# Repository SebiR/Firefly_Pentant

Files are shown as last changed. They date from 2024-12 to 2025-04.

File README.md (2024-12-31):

# Firefly pendant
A green LED inside a small glass bottle looks like a caught firefly.
It is battery powered and can be used as decoration or jewelry.

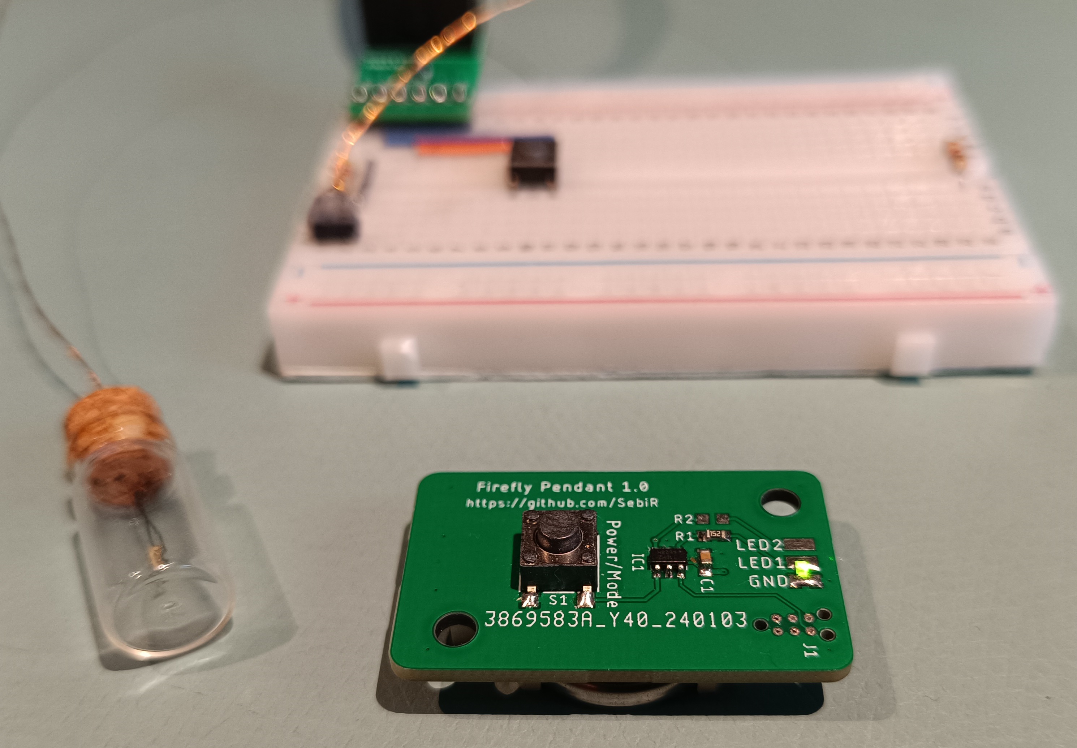
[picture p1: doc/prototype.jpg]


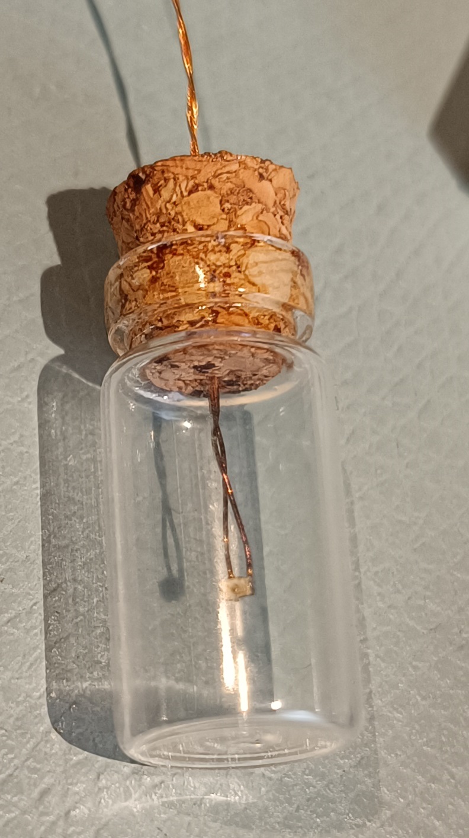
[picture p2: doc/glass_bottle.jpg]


## Features
* powered by a single CR2032
* Can drive two LEDs 
* Can be switched on and off with a button
* Uses deep sleep for long battery life

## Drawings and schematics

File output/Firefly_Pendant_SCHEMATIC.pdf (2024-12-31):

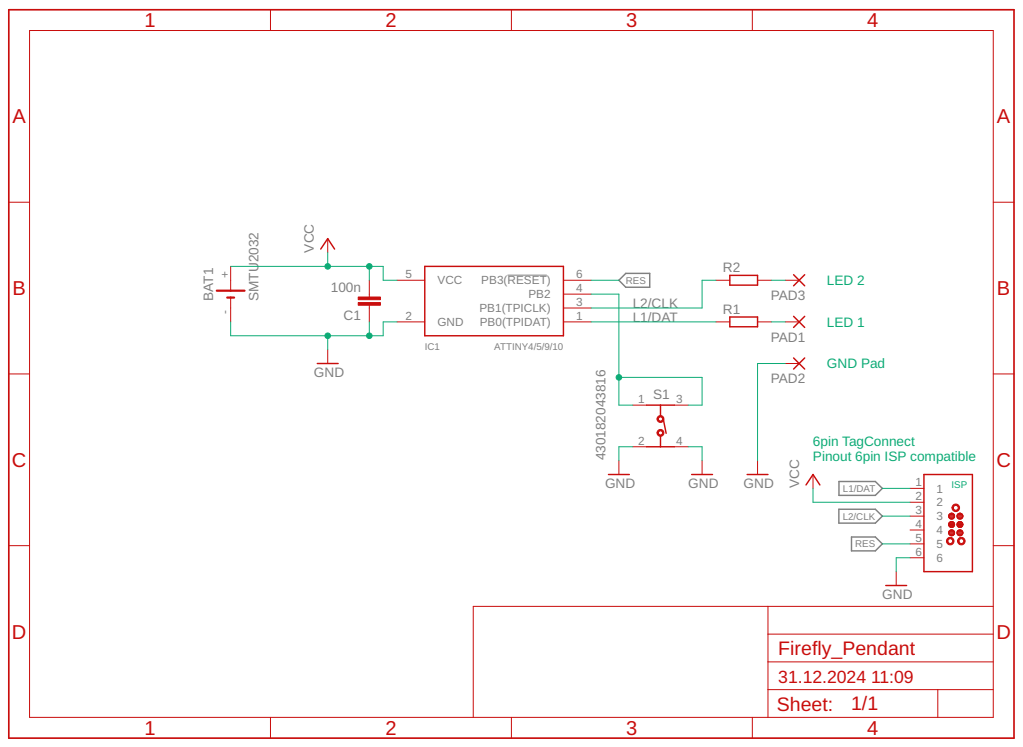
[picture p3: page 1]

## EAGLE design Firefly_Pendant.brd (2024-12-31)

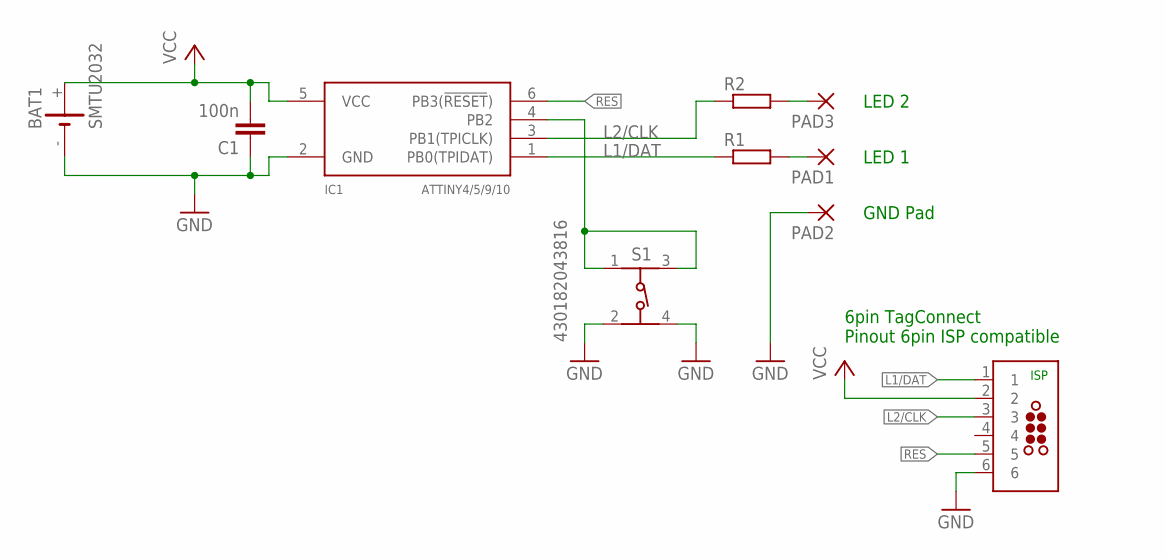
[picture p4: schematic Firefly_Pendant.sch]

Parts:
BAT1: SMTU2032
C1: 100n; C0603
IC1: ATTINY4/5/9/10; SOT23-6
J1: TAG-CONNECT_TC2030-MCP-NL
PAD1, PAD2, PAD3: WIREPADSMD1,27-254; SMD1,27-2,54
R1, R2: R-EU_R0603; R0603
S1: 430182043816

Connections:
GND: BAT1.-, C1.1, IC1.2 (GND), J1.6, PAD2.1, S1.2, S1.4
L1/DAT: IC1.1 (PB0(TPIDAT)), J1.1, R1.1
L2/CLK: IC1.3 (PB1(TPICLK)), J1.3, R2.1
unnamed: PAD1.1, R1.2
unnamed: IC1.4 (PB2), S1.1, S1.3
unnamed: PAD3.1, R2.2
RES: IC1.6 (PB3(!RESET!)), J1.5
VCC: BAT1.+, C1.2, IC1.5 (VCC), J1.2

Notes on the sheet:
ISP
6pin TagConnect Pinout 6pin ISP compatible
GND Pad
LED 1
LED 2

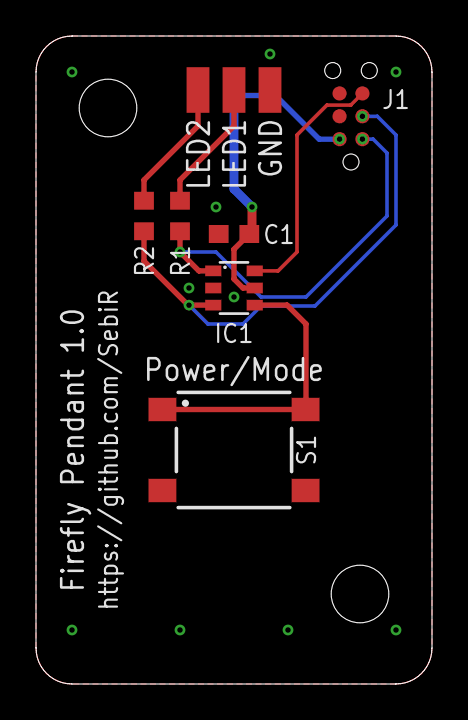
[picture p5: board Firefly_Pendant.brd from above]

Board: 2 copper layers, 22.0 x 36.0 mm, 10 parts (1 on the bottom side), 8 nets.

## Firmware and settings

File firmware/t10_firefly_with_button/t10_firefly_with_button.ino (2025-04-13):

#ifdef F_CPU
#undef F_CPU
#define F_CPU 32000UL
#endif

#include <avr/io.h>
#include <avr/interrupt.h>
#include <avr/sleep.h>
#include <util/delay.h>

#define LED1_PIN PB0    // LED connected to PB0
#define LED2_PIN PB1    // LED connected to PB0
#define BUTTON_PIN PB2  // Button connected to PB2

// uncomment if you want to manually calibrate the internal clock (WDT clock is independent)
//#define CLOCKCAL

volatile uint8_t button_pressed = 0;  // Flag to track button press

// Blink pattern. Each bit is checked with every watch-dog interrupt (currently every ~125ms) and the LED is set according to the bit status
// So 32bit are roughly 4 seconds of pattern
//uint32_t blink_pattern = 0b11001100110011001100110011001100;
//uint32_t blink_pattern = 0b01010101010101010101010101010101;
uint32_t blink_pattern = 0b10100100000000100100010000000000;

void setup() {
  // Disable interrupts
  cli();

  // Configure Watchdog Timer to trigger every ~125ms
  CCP = 0xD8;                                                                                 // Enable confic changes
  WDTCSR = (1 << WDIE) | (0 << WDE) | (0 << WDP3) | (0 << WDP2) | (1 << WDP1) | (1 << WDP0);  // Enable WDT every ~125ms

  // Configure LED pins as outputs
  DDRB |= (1 << LED1_PIN) | (1 << LED2_PIN);
  PORTB &= ~(1 << LED1_PIN) | ~(1 << LED2_PIN);  // Start with LED off

  // Configure PB2 as input with internal pull-up for button
  DDRB &= ~(1 << BUTTON_PIN);  // Set PB2 as input
  PUEB |= (1 << BUTTON_PIN);   // Enable pull-up resistor on PB2

  // Enable pin change interrupt for PB2
  PCICR |= (1 << PCIE0);       // Enable pin change interrupt
  PCMSK |= (1 << BUTTON_PIN);  // Enable interrupt on PB2

  // Disable unused peripherals to save more power
  ADCSRA &= ~(1 << ADEN);  // Disable ADC
  ACSR |= (1 << ACD);      // Disable Analog Comparator

  PRR = (1 << PRADC) | (1 << PRTIM0);  // Shut down ADC and Timer0

  CCP = 0xD8;                              // Unprotect CLKMSR reg
  CLKMSR = (0 << CLKMS1) | (1 << CLKMS0);  // Set Clock source to 128kHz WDT oscillator

  CCP = 0xD8;                                                              // Unprotect CLKPSR reg
  CLKPSR = (0 << CLKPS3) | (0 << CLKPS2) | (1 << CLKPS1) | (0 << CLKPS0);  // Divide Clock by 4 -> 32kHz
  OSCCAL = 0x96;                                                           // Adjusts int. RC clock, irrelevant, as we're using the WDT clock

  // enable global interrupts
  sei();

// LED 100ms on and off, can be used to calibrate OSCCAL
#ifdef CLOCKCAL
  while (1) {
    PORTB |= (1 << LED1_PIN);
    _delay_ms(100);
    PORTB &= ~(1 << LED1_PIN);
    _delay_ms(100);
  }
#endif

  // Set up sleep mode to power down
  set_sleep_mode(SLEEP_MODE_PWR_DOWN);

  // Enable global interrupts
  sei();
}

// Pin Change Interrupt for the mode button
ISR(PCINT0_vect) {
  // Debounce the button
  _delay_ms(500);

  if (!(PINB & (1 << BUTTON_PIN))) {  // Check if button is still pressed
    button_pressed = 1;               // Set flag to toggle LED
  }
}

// Watchdog Trigger Interrupt
ISR(WDT_vect) {
  static uint8_t current_bit = 0;  // Track the current bit position

  // Extract the current bit from the pattern
  uint8_t bit_state = (blink_pattern >> (31 - current_bit)) & 0x01;

  // Set or clear the LED based on the bit value
  if (bit_state) {
    PORTB |= (1 << LED1_PIN);  // Turn on the LED
  } else {
    PORTB &= ~(1 << LED1_PIN);  // Turn off the LED
  }

  // Move to the next bit
  current_bit++;
  if (current_bit > 31) {
    current_bit = 0;  // Wrap around to the start of the pattern
  }
}

void loop() {
  // Check if button was pressed
  if (button_pressed) {
    button_pressed = 0;  // Clear the flag

    // Toggle WDT enable
    WDTCSR ^= (1 << WDIE);

    // LED off
    PORTB &= ~(1 << LED1_PIN);

    // Add a small delay to debounce further presses
    _delay_ms(50);
  }

  // Enter sleep mode
  sleep_mode();

  // Execution resumes here after waking up
}

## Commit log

2024-12-31 Scaled down clock a lot to save more power
2025-01-06 Moved from internal RC oscillator to WDT oscillator to save even more current
    [t10_firefly_with_button.ino]
2025-01-06 Used PRR (power reduction register) to shut down ADC and Timer0

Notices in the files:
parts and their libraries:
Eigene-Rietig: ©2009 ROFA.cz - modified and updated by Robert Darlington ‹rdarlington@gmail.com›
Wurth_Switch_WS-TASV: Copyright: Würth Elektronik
